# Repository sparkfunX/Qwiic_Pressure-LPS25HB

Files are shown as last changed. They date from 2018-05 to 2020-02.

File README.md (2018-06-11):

SparkFun Qwiic Pressure with LPS25HB
========================================

Qwiic Pressure Sensor - LPS25HB

[*Qwiic Pressure Sensor - LPS25HB (SPX-14767)*](https://www.sparkfun.com/products/14767)

The LPS25HB is an absolute pressure sensor which means that it has an internal vacuum as a reference. (As opposed to *differential* and *gage* sensors, see [this](https://cdn.sparkfun.com/assets/e/1/2/4/1/HoneywellTechnicalNote_Absolute_v_Gage_pressure.pdf) description by Honeywell for more info) Absolute pressure sensors are often used as altimeters however they can be seen in other applications like the [Robotic Finger Sensor v2](https://www.sparkfun.com/products/14687). 

You can use this absolute pressure sensor to inform a drone autopilot of altitude, make a personal weather station, or maybe even help test someone's lung function! As part of the Qwiic system adding more capabilities like data logging with the [Qwiic OpenLog](https://www.sparkfun.com/products/14641) is a cinch!

The LPS25HB is the newest version of the LPS25H by STMicroelectronics featuring the widest range of sensing pressures (26 kPa to 126 kPa) and very high precision (as low as 1 Pa RMS, which equates to approximately 8 centimeters of air at sea level). Other features such as the 25 Hz update rate and durability to withstand nearly 2.5 MPa over-pressure make this a great choice for absolute pressure sensor. Additionally the LPS25HB comes in a stylish plastic IC package, as opposed to the standard metal casing seen on most other pressure sensors.

In addition to the Qwiic connectors this sensor breakout exposes the I2C and SPI lines as plated through hole (PTH) connections on either side. SPI access will allow for even faster communication with the sensor (up to 10 MHz!) 

This board is one of our many [Qwiic](https://www.sparkfun.com/qwiic) compatible boards! Simply plug and go. No soldering, no figuring out which is SDA or SCL, and no voltage regulation or translation required!

SparkFun labored with love to create this code. Feel like supporting open source hardware? 
Buy a [breakout board](https://www.sparkfun.com/products/14688) from SparkFun!

Repository Contents
-------------------

* **/Documents** - Datasheets
* **/Hardware** - Eagle design files (.brd, .sch)

Library
--------------
* **[Arduino Library](https://github.com/sparkfun/SparkFun_LPS25HB_Arduino_Library)** - Library for reading pressure and changing sensor settings

License Information
-------------------

This product is _**open source**_! 

If you have any questions or concerns on licensing, please contact techsupport@sparkfun.com.

Please use, reuse, and modify these files as you see fit. Please maintain attribution to SparkFun Electronics and release any derivative under the same license.

Distributed as-is; no warranty is given.

- Your friends at SparkFun.

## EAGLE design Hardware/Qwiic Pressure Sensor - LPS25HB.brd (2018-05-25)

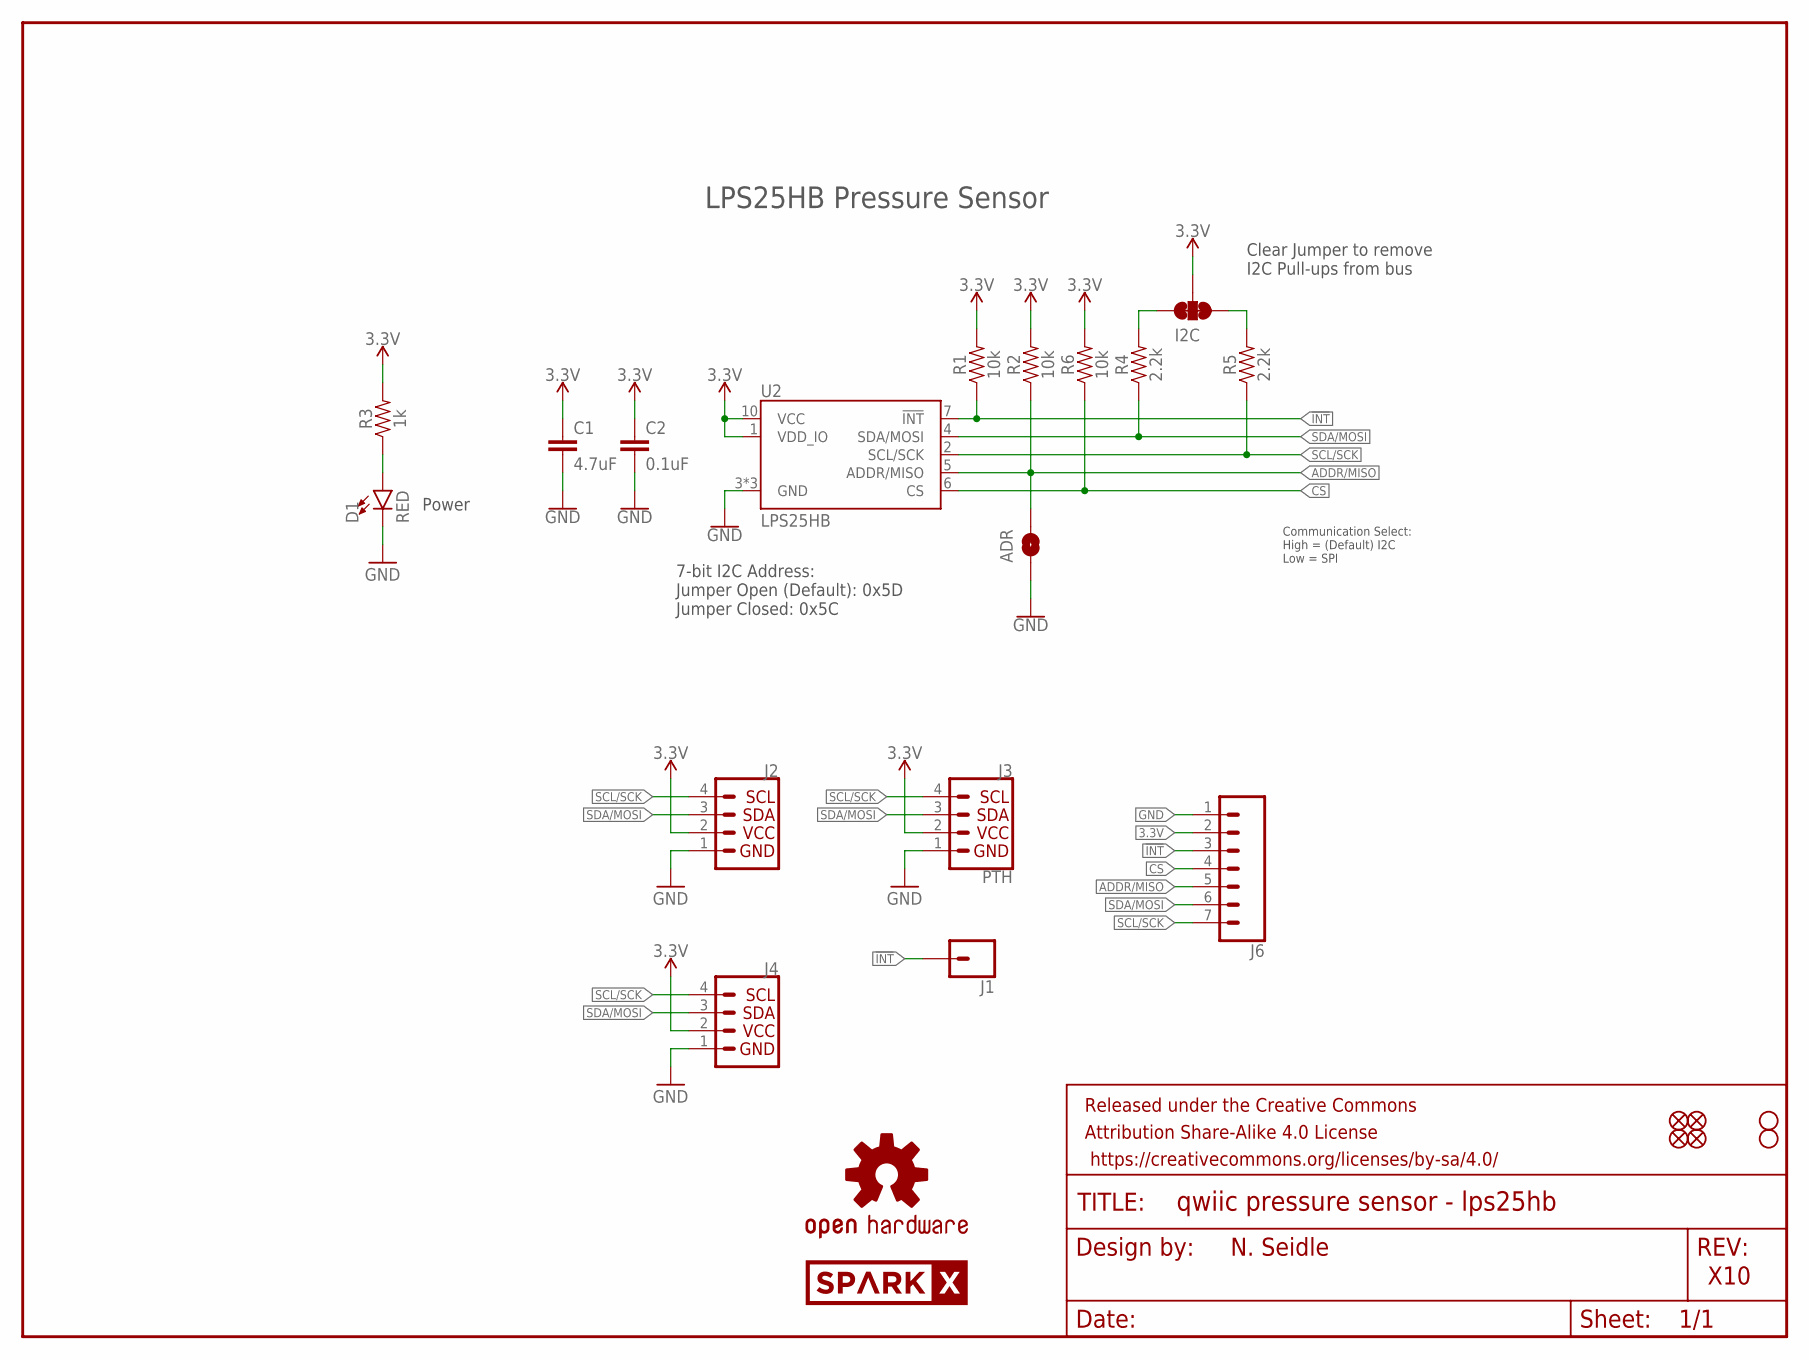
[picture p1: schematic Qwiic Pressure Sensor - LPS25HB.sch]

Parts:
ADR: JUMPER-SMT_2_NO_SILK; SMT-JUMPER_2_NO_SILK
C1: 4.7uF; 0603
C2: 0.1uF; 0603
D1: RED; LED-0603
FRAME1: FRAME-LETTER; CREATIVE_COMMONS
I2C: JUMPER-SMT_3_2-NC_TRACE_SILK; SMT-JUMPER_3_2-NC_TRACE_SILK
J1: CONN_01PTH_NO_SILK_YES_STOP; 1X01_NO_SILK
J2, J4: I2C_STANDARDQWIIC; 1X04_1MM_RA
J3: PTH; 1X04_NO_SILK
J6: CONN_07NO_SILK; 1X07_NO_SILK
JP1, JP2, JP5, JP6: FIDUCIALUFIDUCIAL; MICRO-FIDUCIAL
JP3, JP4: STAND-OFF
LOGO1: OSHW-LOGOMINI; OSHW-LOGO-MINI
R1, R2, R6: 10k; 0603
R3: 1k; 0603
R4, R5: 2.2k; 0603
U2: LPS25HB
U$2: SPARKX-LOGO4; SPARKX-MEDIUM

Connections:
3.3V: C1.1, C2.1, I2C.2, J2.2, J3.2 (VCC), J4.2, J6.2, R1.2, R2.2, R3.2, R6.2, U2.1 (VDD_IO), U2.10 (VCC)
!INT: J1.1, J6.3, R1.1, U2.7 (!INT)
ADDR/MISO: ADR.2, J6.5, R2.1, U2.5 (ADDR/MISO)
CS: J6.4, R6.1, U2.6 (CS)
GND: ADR.1, C1.2, C2.2, D1.C, J2.1, J3.1 (GND), J4.1, J6.1, U2.3 (GND), U2.8 (GND), U2.9 (GND)
unnamed: I2C.1, R5.2
unnamed: I2C.3, R4.2
unnamed: D1.A, R3.1
SCL/SCK: J2.4, J3.4 (SCL), J4.4, J6.7, R5.1, U2.2 (SCL/SCK)
SDA/MOSI: J2.3, J3.3 (SDA), J4.3, J6.6, R4.1, U2.4 (SDA/MOSI)

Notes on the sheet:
N. Seidle
X10
Clear Jumper to remove I2C Pull-ups from bus
Power
LPS25HB Pressure Sensor
7-bit I2C Address: Jumper Open (Default): 0x5D Jumper Closed: 0x5C
Communication Select: High = (Default) I2C Low = SPI

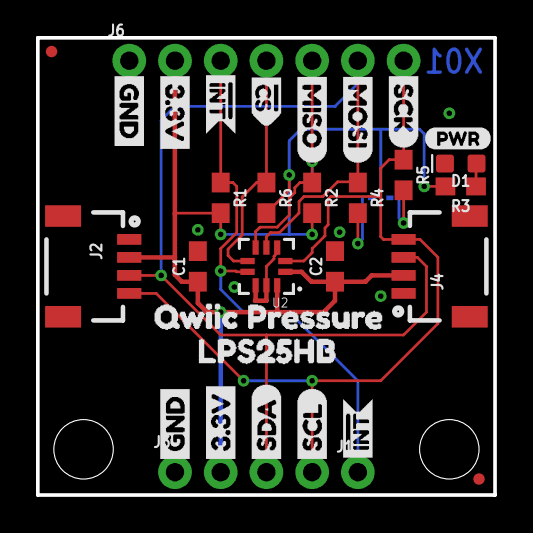
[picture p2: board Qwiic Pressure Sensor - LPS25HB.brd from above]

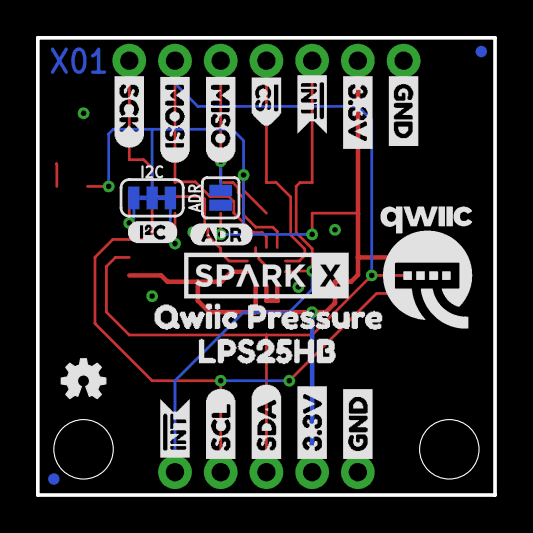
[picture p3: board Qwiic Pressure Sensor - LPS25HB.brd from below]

Board: 2 copper layers, 25.4 x 25.4 mm, 58 parts (23 on the bottom side), 10 nets.

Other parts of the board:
U$1, U$37: QWIIC_PRESSURE1
U$3, U$22, U$31, U$32: GND1
U$4, U$21, U$30, U$33: 3#3V2
U$5, U$27: SDA8
U$6, U$26: SCL9
U$7, U$35: LPS25HB0
U$9: QWIIC-LOGO-MEDIUM
U$10, U$11: MISO
U$12: I_SUPER2_C-()-03
U$15: PWR-()-03
U$16, U$17: MOSI
U$18, U$19: SCK-[)
U$20, U$23: CS#-[>
U$24, U$25, U$28, U$29: INT#-[<
U$34: ADR-()-03

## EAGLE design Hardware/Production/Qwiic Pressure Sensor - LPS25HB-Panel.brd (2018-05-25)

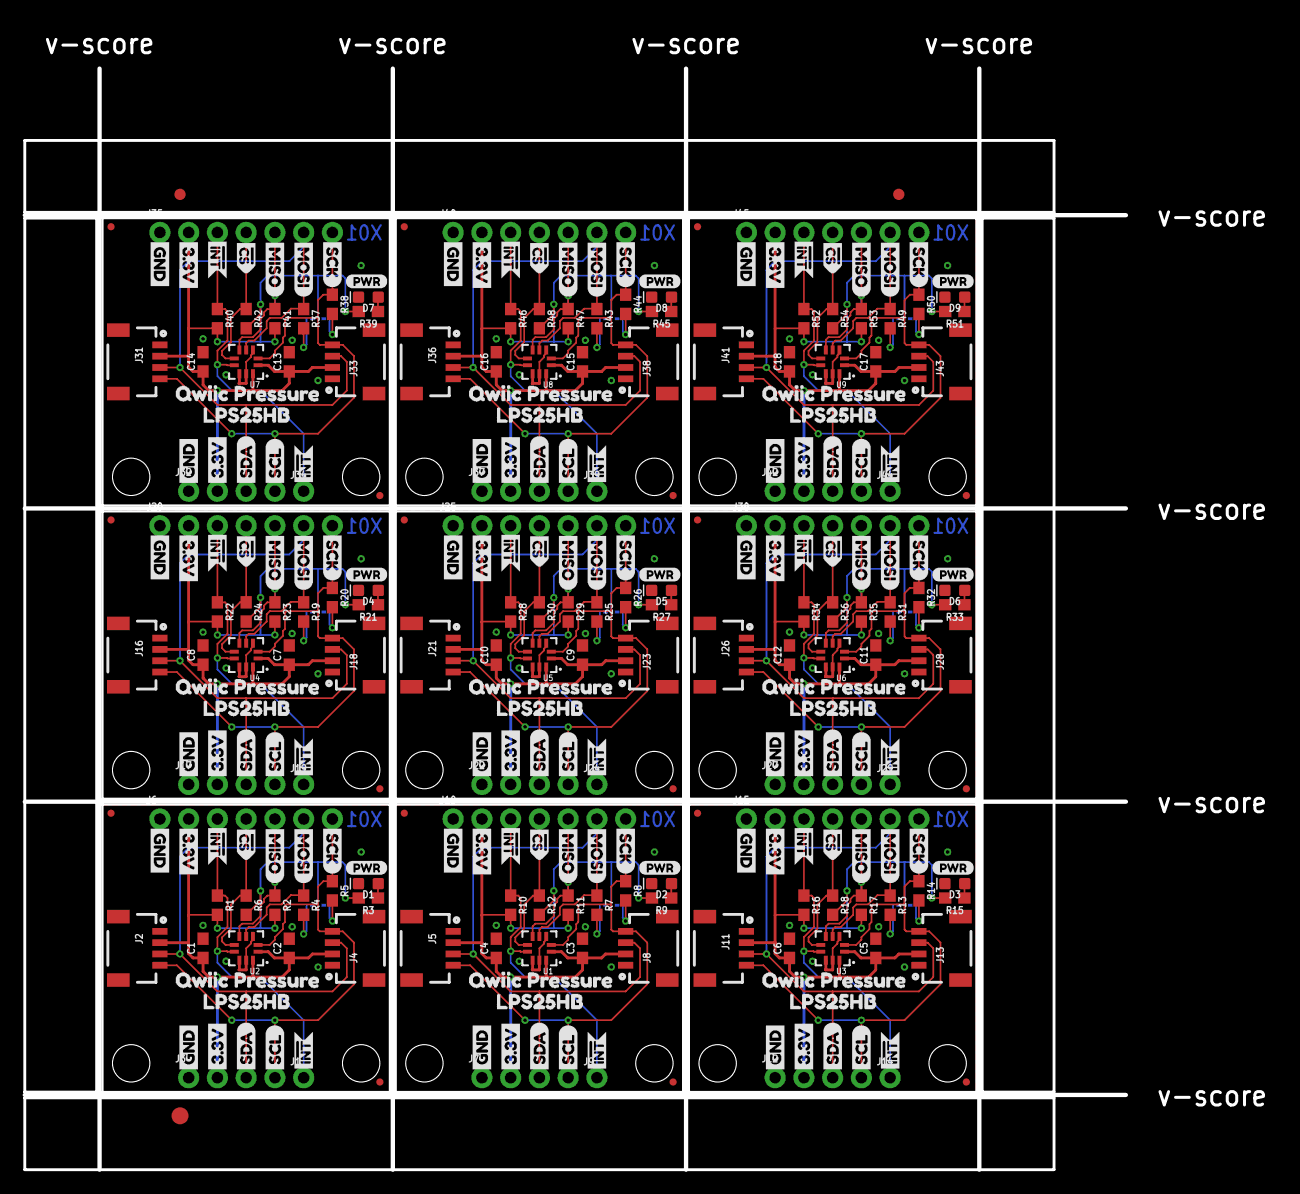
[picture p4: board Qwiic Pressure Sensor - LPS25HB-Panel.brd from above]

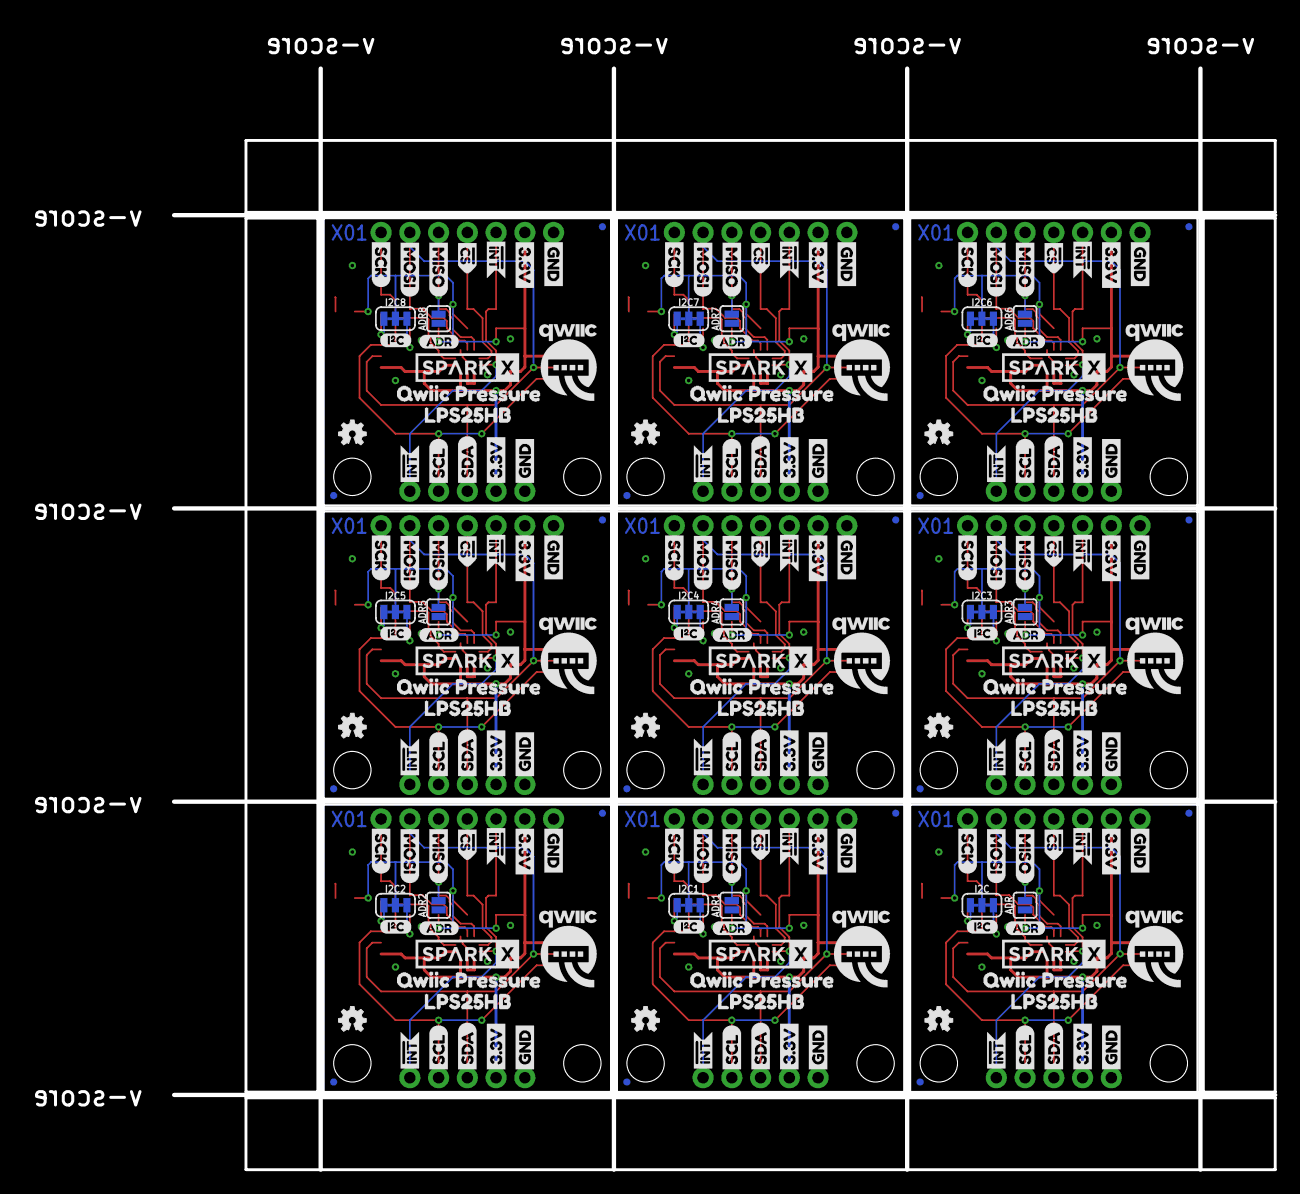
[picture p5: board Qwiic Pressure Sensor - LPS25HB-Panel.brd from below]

Board: 2 copper layers, 97.3 x 97.3 mm, 516 parts (207 on the bottom side), 90 nets.

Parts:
ADR, ADR1, ADR2, ADR3, ADR4, ADR5, ADR6, ADR7, ADR8: SMT-JUMPER_2_NO_SILK
C1, C4, C6, C8, C10, C12, C14, C16, C18: 4.7uF; 0603
C2, C3, C5, C7, C9, C11, C13, C15, C17: 0.1uF; 0603
D1, D2, D3, D4, D5, D6, D7, D8, D9: RED; LED-0603
E$1, E$2: FIDUCIAL-1X2
E$3: FIDUCIAL-1.5X3
I2C, I2C1, I2C2, I2C3, I2C4, I2C5, I2C6, I2C7, I2C8: SMT-JUMPER_3_2-NC_TRACE_SILK
J1, J9, J14, J19, J24, J29, J34, J39, J44: 1X01_NO_SILK
J2, J4, J5, J8, J11, J13, J16, J18, J21, J23, J26, J28, J31, J33, J36, J38, J41, J43: 1X04_1MM_RA
J3, J7, J12, J17, J22, J27, J32, J37, J42: PTH; 1X04_NO_SILK
J6, J10, J15, J20, J25, J30, J35, J40, J45: 1X07_NO_SILK
JP1, JP2, JP5, JP6, JP9, JP10, JP11, JP12, JP15, JP16, JP17, JP18, JP21, JP22, JP23, JP24, JP27, JP28, JP29, JP30, JP33, JP34, JP35, JP36, JP39, JP40, JP41, JP42, JP45, JP46, JP47, JP48, JP51, JP52, JP53, JP54: FIDUCIALUFIDUCIAL; MICRO-FIDUCIAL
JP3, JP4, JP7, JP8, JP13, JP14, JP19, JP20, JP25, JP26, JP31, JP32, JP37, JP38, JP43, JP44, JP49, JP50: STAND-OFF
LOGO1, LOGO2, LOGO3, LOGO4, LOGO5, LOGO6, LOGO7, LOGO8, LOGO9: OSHW-LOGOMINI; OSHW-LOGO-MINI
R1, R2, R6, R10, R11, R12, R16, R17, R18, R22, R23, R24, R28, R29, R30, R34, R35, R36, R40, R41, R42, R46, R47, R48, R52, R53, R54: 10k; 0603
R3, R9, R15, R21, R27, R33, R39, R45, R51: 1k; 0603
R4, R5, R7, R8, R13, R14, R19, R20, R25, R26, R31, R32, R37, R38, R43, R44, R49, R50: 2.2k; 0603
U1, U2, U3, U4, U5, U6, U7, U8, U9: LPS25HB
U$1, U$37, U$64, U$65, U$97, U$98, U$130, U$131, U$163, U$164, U$196, U$197, U$229, U$230, U$262, U$263, U$295, U$296: QWIIC_PRESSURE1
U$2, U$8, U$67, U$100, U$133, U$166, U$199, U$232, U$265: SPARKX-LOGO4; SPARKX-MEDIUM
U$3, U$14, U$22, U$31, U$32, U$39, U$59, U$60, U$69, U$72, U$92, U$93, U$102, U$105, U$125, U$126, U$135, U$138, U$158, U$159, U$168, U$171, U$191, U$192, U$201, U$204, U$224, U$225, U$234, U$237, U$257, U$258, U$267, U$270, U$290, U$291: GND1
U$4, U$13, U$21, U$30, U$33, U$40, U$58, U$61, U$68, U$73, U$91, U$94, U$101, U$106, U$124, U$127, U$134, U$139, U$157, U$160, U$167, U$172, U$190, U$193, U$200, U$205, U$223, U$226, U$233, U$238, U$256, U$259, U$266, U$271, U$289, U$292: 3#3V2
U$5, U$27, U$38, U$41, U$71, U$74, U$104, U$107, U$137, U$140, U$170, U$173, U$203, U$206, U$236, U$239, U$269, U$272: SDA8
U$6, U$26, U$36, U$42, U$70, U$75, U$103, U$108, U$136, U$141, U$169, U$174, U$202, U$207, U$235, U$240, U$268, U$273: SCL9
U$7, U$35, U$63, U$66, U$96, U$99, U$129, U$132, U$162, U$165, U$195, U$198, U$228, U$231, U$261, U$264, U$294, U$297: LPS25HB0
U$9, U$43, U$76, U$109, U$142, U$175, U$208, U$241, U$274: QWIIC-LOGO-MEDIUM
U$10, U$11, U$46, U$47, U$79, U$80, U$112, U$113, U$145, U$146, U$178, U$179, U$211, U$212, U$244, U$245, U$277, U$278: MISO
U$12, U$44, U$77, U$110, U$143, U$176, U$209, U$242, U$275: I_SUPER2_C-()-03
U$15, U$45, U$78, U$111, U$144, U$177, U$210, U$243, U$276: PWR-()-03
U$16, U$17, U$48, U$49, U$81, U$82, U$114, U$115, U$147, U$148, U$180, U$181, U$213, U$214, U$246, U$247, U$279, U$280: MOSI
U$18, U$19, U$50, U$51, U$83, U$84, U$116, U$117, U$149, U$150, U$182, U$183, U$215, U$216, U$248, U$249, U$281, U$282: SCK-[)
U$20, U$23, U$52, U$53, U$85, U$86, U$118, U$119, U$151, U$152, U$184, U$185, U$217, U$218, U$250, U$251, U$283, U$284: CS#-[>
U$24, U$25, U$28, U$29, U$54, U$55, U$56, U$57, U$87, U$88, U$89, U$90, U$120, U$121, U$122, U$123, U$153, U$154, U$155, U$156, U$186, U$187, U$188, U$189, U$219, U$220, U$221, U$222, U$252, U$253, U$254, U$255, U$285, U$286, U$287, U$288: INT#-[<
U$34, U$62, U$95, U$128, U$161, U$194, U$227, U$260, U$293: ADR-()-03

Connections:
3.3V: C1.1, C2.1, I2C.2, J2.2, J3.2, J4.2, J6.2, R1.2, R2.2, R3.2, R6.2, U2.1, U2.10
3.3V1: C3.1, C4.1, I2C1.2, J5.2, J7.2, J8.2, J10.2, R9.2, R10.2, R11.2, R12.2, U1.1, U1.10
3.3V2: C5.1, C6.1, I2C2.2, J11.2, J12.2, J13.2, J15.2, R15.2, R16.2, R17.2, R18.2, U3.1, U3.10
3.3V3: C7.1, C8.1, I2C3.2, J16.2, J17.2, J18.2, J20.2, R21.2, R22.2, R23.2, R24.2, U4.1, U4.10
3.3V4: C9.1, C10.1, I2C4.2, J21.2, J22.2, J23.2, J25.2, R27.2, R28.2, R29.2, R30.2, U5.1, U5.10
3.3V5: C11.1, C12.1, I2C5.2, J26.2, J27.2, J28.2, J30.2, R33.2, R34.2, R35.2, R36.2, U6.1, U6.10
3.3V6: C13.1, C14.1, I2C6.2, J31.2, J32.2, J33.2, J35.2, R39.2, R40.2, R41.2, R42.2, U7.1, U7.10
3.3V7: C15.1, C16.1, I2C7.2, J36.2, J37.2, J38.2, J40.2, R45.2, R46.2, R47.2, R48.2, U8.1, U8.10
3.3V8: C17.1, C18.1, I2C8.2, J41.2, J42.2, J43.2, J45.2, R51.2, R52.2, R53.2, R54.2, U9.1, U9.10
!INT: J1.1, J6.3, R1.1, U2.7
!INT1: J9.1, J10.3, R10.1, U1.7
!INT2: J14.1, J15.3, R16.1, U3.7
!INT3: J19.1, J20.3, R22.1, U4.7
!INT4: J24.1, J25.3, R28.1, U5.7
!INT5: J29.1, J30.3, R34.1, U6.7
!INT6: J34.1, J35.3, R40.1, U7.7
!INT7: J39.1, J40.3, R46.1, U8.7
!INT8: J44.1, J45.3, R52.1, U9.7
ADDR/MISO: ADR.2, J6.5, R2.1, U2.5
ADDR/MISO1: ADR1.2, J10.5, R11.1, U1.5
ADDR/MISO2: ADR2.2, J15.5, R17.1, U3.5
ADDR/MISO3: ADR3.2, J20.5, R23.1, U4.5
ADDR/MISO4: ADR4.2, J25.5, R29.1, U5.5
ADDR/MISO5: ADR5.2, J30.5, R35.1, U6.5
ADDR/MISO6: ADR6.2, J35.5, R41.1, U7.5
ADDR/MISO7: ADR7.2, J40.5, R47.1, U8.5
ADDR/MISO8: ADR8.2, J45.5, R53.1, U9.5
CS: J6.4, R6.1, U2.6
CS1: J10.4, R12.1, U1.6
CS2: J15.4, R18.1, U3.6
CS3: J20.4, R24.1, U4.6
CS4: J25.4, R30.1, U5.6
CS5: J30.4, R36.1, U6.6
CS6: J35.4, R42.1, U7.6
CS7: J40.4, R48.1, U8.6
CS8: J45.4, R54.1, U9.6
GND: ADR.1, C1.2, C2.2, D1.C, J2.1, J3.1, J4.1, J6.1, U2.3, U2.8, U2.9
GND1: ADR1.1, C3.2, C4.2, D2.C, J5.1, J7.1, J8.1, J10.1, U1.3, U1.8, U1.9
GND2: ADR2.1, C5.2, C6.2, D3.C, J11.1, J12.1, J13.1, J15.1, U3.3, U3.8, U3.9
GND3: ADR3.1, C7.2, C8.2, D4.C, J16.1, J17.1, J18.1, J20.1, U4.3, U4.8, U4.9
GND4: ADR4.1, C9.2, C10.2, D5.C, J21.1, J22.1, J23.1, J25.1, U5.3, U5.8, U5.9
GND5: ADR5.1, C11.2, C12.2, D6.C, J26.1, J27.1, J28.1, J30.1, U6.3, U6.8, U6.9
GND6: ADR6.1, C13.2, C14.2, D7.C, J31.1, J32.1, J33.1, J35.1, U7.3, U7.8, U7.9
GND7: ADR7.1, C15.2, C16.2, D8.C, J36.1, J37.1, J38.1, J40.1, U8.3, U8.8, U8.9
GND8: ADR8.1, C17.2, C18.2, D9.C, J41.1, J42.1, J43.1, J45.1, U9.3, U9.8, U9.9
unnamed: I2C.1, R5.2
unnamed: I2C.3, R4.2
unnamed: D1.A, R3.1
unnamed: I2C1.1, R8.2
unnamed: I2C1.3, R7.2
unnamed: D2.A, R9.1
unnamed: I2C2.1, R14.2
unnamed: I2C2.3, R13.2
unnamed: D3.A, R15.1
unnamed: I2C3.1, R20.2
unnamed: I2C3.3, R19.2
unnamed: D4.A, R21.1
unnamed: I2C4.1, R26.2
unnamed: I2C4.3, R25.2
unnamed: D5.A, R27.1
unnamed: I2C5.1, R32.2
unnamed: I2C5.3, R31.2
unnamed: D6.A, R33.1
unnamed: I2C6.1, R38.2
unnamed: I2C6.3, R37.2
unnamed: D7.A, R39.1
unnamed: I2C7.1, R44.2
unnamed: I2C7.3, R43.2
unnamed: D8.A, R45.1
unnamed: I2C8.1, R50.2
unnamed: I2C8.3, R49.2
unnamed: D9.A, R51.1
SCL/SCK: J2.4, J3.4, J4.4, J6.7, R5.1, U2.2
SCL/SCK1: J5.4, J7.4, J8.4, J10.7, R8.1, U1.2
SCL/SCK2: J11.4, J12.4, J13.4, J15.7, R14.1, U3.2
SCL/SCK3: J16.4, J17.4, J18.4, J20.7, R20.1, U4.2
SCL/SCK4: J21.4, J22.4, J23.4, J25.7, R26.1, U5.2
SCL/SCK5: J26.4, J27.4, J28.4, J30.7, R32.1, U6.2
SCL/SCK6: J31.4, J32.4, J33.4, J35.7, R38.1, U7.2
SCL/SCK7: J36.4, J37.4, J38.4, J40.7, R44.1, U8.2
SCL/SCK8: J41.4, J42.4, J43.4, J45.7, R50.1, U9.2
SDA/MOSI: J2.3, J3.3, J4.3, J6.6, R4.1, U2.4
SDA/MOSI1: J5.3, J7.3, J8.3, J10.6, R7.1, U1.4
SDA/MOSI2: J11.3, J12.3, J13.3, J15.6, R13.1, U3.4
SDA/MOSI3: J16.3, J17.3, J18.3, J20.6, R19.1, U4.4
SDA/MOSI4: J21.3, J22.3, J23.3, J25.6, R25.1, U5.4
SDA/MOSI5: J26.3, J27.3, J28.3, J30.6, R31.1, U6.4
SDA/MOSI6: J31.3, J32.3, J33.3, J35.6, R37.1, U7.4
SDA/MOSI7: J36.3, J37.3, J38.3, J40.6, R43.1, U8.4
SDA/MOSI8: J41.3, J42.3, J43.3, J45.6, R49.1, U9.4

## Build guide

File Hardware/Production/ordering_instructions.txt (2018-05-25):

panel size, 91x91mm
PCB thickness, 1.6mm
number of layers, 2
soldermask color, Black
silkscreen color, White
oz copper, 1oz
finish, HASL lead free
stencils, none
pcs per panel, 9

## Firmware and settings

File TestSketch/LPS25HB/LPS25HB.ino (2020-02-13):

/*
  Simple, quick test sketch.
*/

#include <SparkFun_LPS25HB_Arduino_Library.h> //Click here to get the library: http://librarymanager/All#SparkFun_LPS25HB

LPS25HB pressureSensor; // Create an object of the LPS25HB class

#define statLED 5

void setup()
{
  Serial.begin(115200);
  Serial.println("LPS25HB Pressure Sensor Example 1 - Basic Readings");
  Serial.println();
  pinMode(statLED, OUTPUT);
  digitalWrite(statLED, LOW);

  Wire.begin();
}

void loop()
{
  if (pressureSensor.begin() == true) // The library supports some different error codes such as "DISCONNECTED"
  {
    float temperature = pressureSensor.getTemperature_degC();
    float pressure = pressureSensor.getPressure_hPa();

    //pressureSensor.begin(); // Begin links an I2C port and I2C address to the sensor, sets an I2C speed, begins I2C on the main board, and then sets default settings
    Serial.print("Pressure in hPa: ");
    Serial.print(pressure); // Get the pressure reading in hPa
    Serial.print(", Temperature (degC): ");
    Serial.println(temperature, 2); // Get the temperature in degrees C

    if (pressure < 870.0 && pressure > 840.0 && temperature < 29 && temperature > 24)
      digitalWrite(statLED, HIGH);

  }
  else
  {
    Serial.println("Nothing detected");
    digitalWrite(statLED, LOW);
  }

  delay(100); // Wait - 40 ms corresponds to the maximum update rate of the sensor (25 Hz)
}

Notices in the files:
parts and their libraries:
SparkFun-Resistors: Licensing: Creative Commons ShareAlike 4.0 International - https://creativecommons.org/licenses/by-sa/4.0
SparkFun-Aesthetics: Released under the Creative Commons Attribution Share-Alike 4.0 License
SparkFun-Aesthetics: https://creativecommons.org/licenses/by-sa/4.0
